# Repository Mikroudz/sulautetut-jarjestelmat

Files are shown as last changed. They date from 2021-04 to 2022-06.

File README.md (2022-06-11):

<!-- PROJECT LOGO -->
<br />
<div align="center">

<h3 align="center">Balancing robot</h3>

  <p align="center">
    Two wheeled balancing robot using 6DoF accelerometer and gyroscope.
  </p>
</div>

<!-- TABLE OF CONTENTS -->
<details>
  <summary>Table of Contents</summary>
  <ol>
    <li>
      <a href="#about-the-project">About The Project</a>
      <ul>
        <li><a href="#built-with">Built With</a></li>
      </ul>
    </li>
    <li>
      <a href="#getting-started">Getting Started</a>
      <ul>
        <li><a href="#prerequisites">Prerequisites</a></li>
        <li><a href="#installation">Installation</a></li>
      </ul>
    </li>
    <li><a href="#usage">Usage</a></li>
    <li><a href="#roadmap">Roadmap</a></li>
    <li><a href="#contributing">Contributing</a></li>
    <li><a href="#license">License</a></li>
    <li><a href="#contact">Contact</a></li>
    <li><a href="#acknowledgments">Acknowledgments</a></li>
  </ol>
</details>

<!-- ABOUT THE PROJECT -->
## About The Project

[![Product Name Screen Shot][product-screenshot]](https://example.com)

<p align="right">(<a href="#top">back to top</a>)</p>

### Built With

* [Visual Studio Code](https://code.visualstudio.com/)
* [Platformio IO](https://platformio.org/)
* [STM32PIO](https://github.com/ussserrr/stm32pio)
* [CubeMX](https://www.st.com/en/development-tools/stm32cubemx.html)

<p align="right">(<a href="#top">back to top</a>)</p>

<!-- GETTING STARTED -->
## Getting Started

Easiest way to develop is with Visual Studio Code and Platformio. Template file generated with CubeMX and converted to VSCode format with STM32PIO. All tools work in both linux and windows operating systems. To program and debug the PCB, stlink interface is used and it requires a Nucleo development board or a Stlink programmer.

### Installation

1. Install Visual Studio Code for your distribution

2. Install Platformio IO inside Visual Studio Code.

3. Clone the project to your local PC
   ```sh
   git clone https://github.com/Mikroudz/sulautetut-jarjestelmat.git
   ```
4. Open project folder "STM32F410" in Visual Studio Code. Platformio should detect the project and install required compilation tools. Wait till it finishes.

## Programming the device
1. Connect a JTAG programming interface to the device and a Nucleo programmir header or JTAG programmer.

2. Power up the PCB with 11 - 16 volt power supply.

3. Insert USB to a pc with Visual Studio and platformio installed. The STM32 programmer should be detected.

4. Compile and program the device by pressing "Program" button in bottom of VSCode screen.

5. If successful the robots led should blink slowly.

<p align="right">(<a href="#top">back to top</a>)</p>

### Making configuration changes

To change I/O port configurations or device clocks, the project has been configured to use CubeMX tool. 
WARNING: if configurations are changed directly in the code, they will be overwritten by CubeMX.

1. Install CubeMX and open STM32F410.ioc file in the program.

2. Make changes and save the file.

3. Run [STM32PIO](https://github.com/ussserrr/stm32pio) on command line to update the project files:
   ```sh
   stm32pio generate -d path/to/ioc/file/folder
   ```

<!-- USAGE EXAMPLES -->
## Usage

After powering the robot and without LoRa connection it should be ready to balance. If the leds are blinking then hold the robot in upright position until it start to balance. If robot falls over too much forward or backwards, it stops the motors. 

<p align="right">(<a href="#top">back to top</a>)</p>

<!-- LICENSE -->
## License

Distributed under the MIT License. See `LICENSE.txt` for more information.

<p align="right">(<a href="#top">back to top</a>)</p>

<!-- ACKNOWLEDGMENTS -->
## Acknowledgments

* [@Mikroudz](https://github.com/Mikroudz)
* [@jruntti20](https://github.com/jruntti20)
* [@valtteriah](https://github.com/valtteriah)

<p align="right">(<a href="#top">back to top</a>)</p>

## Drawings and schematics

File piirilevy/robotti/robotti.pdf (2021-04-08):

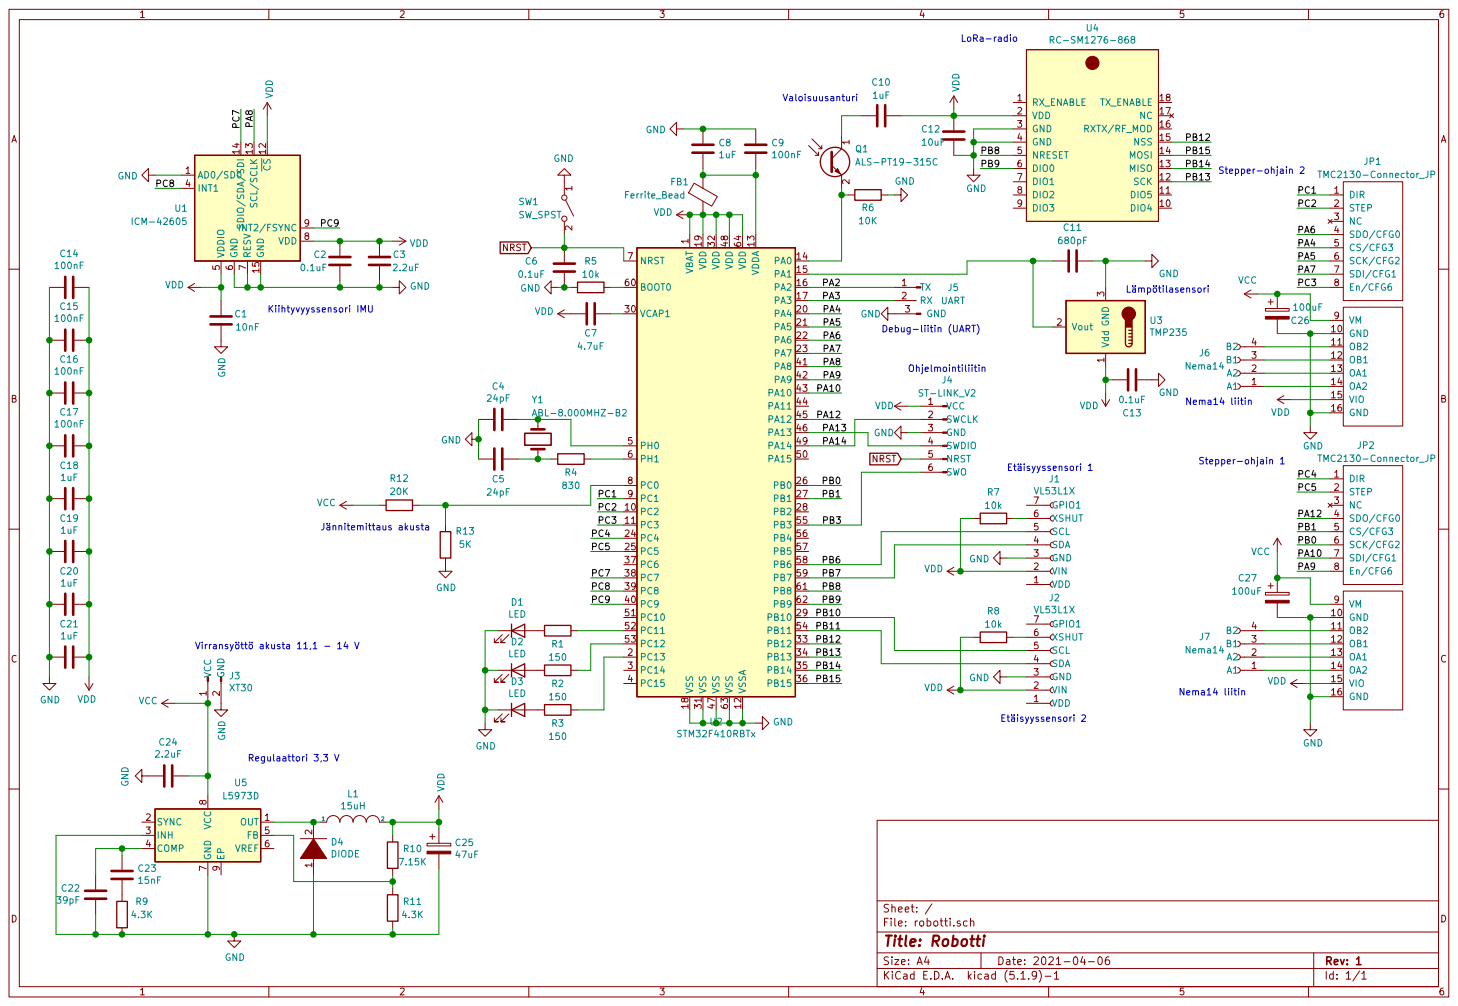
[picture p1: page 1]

LoRa-radioEtäisyyssensori 1
1uF GND
Stepper-ohjain 2 Nema14 liitin Nema14 liitin

1 VCAP1 30 VDD 19 VDD 32 VDD 48 VDD 64 VDDA 13 VSS 18 VSS 31 VSS 47 VSS 63 VSSA 12 U2 STM32F410RBTx

VCC 1 SWCLK 2 GND 3 SWDIO 4 NRST 5 SWO 6

Id: 1/1 Title: Robotti File: robotti.sch Sheet: / R12

VDD 1 VIN 2 GND 3 SDA 4 SCL 5 XSHUT 6 GPIO1 7

Jännitemittaus akusta Virransyöttö akusta 11,1 - 14 V

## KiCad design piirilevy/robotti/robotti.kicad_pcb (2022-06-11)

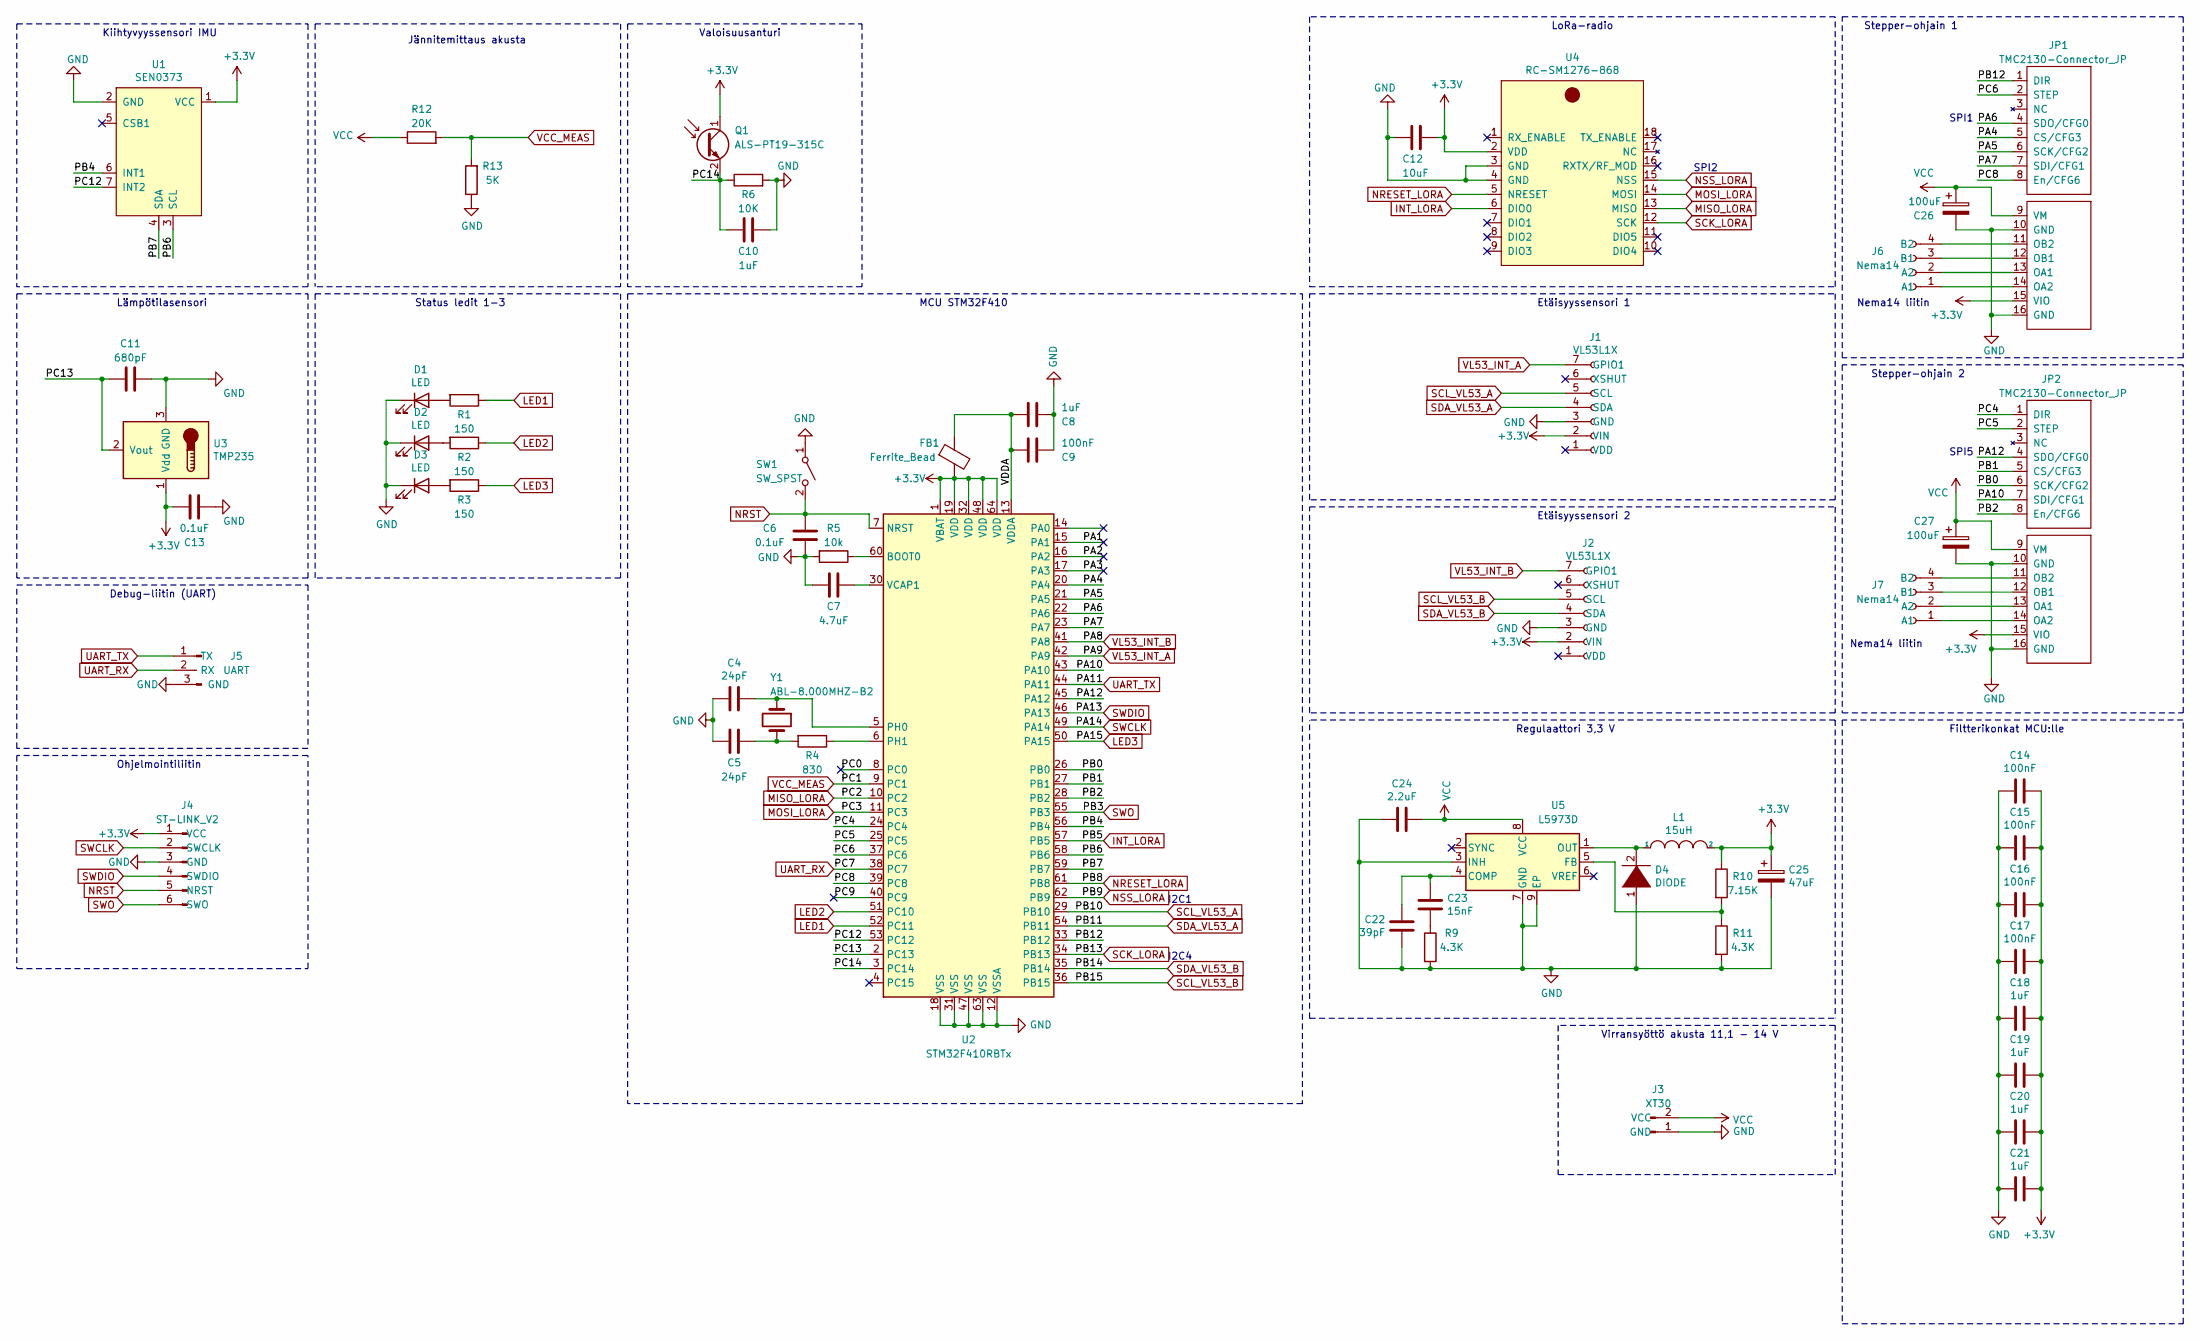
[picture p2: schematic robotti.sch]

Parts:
C4, C5: 24pF; C_0805_2012Metric
C6, C13: 0.1uF; C_0805_2012Metric
C7: 4.7uF; C_0805_2012Metric
C8, C10, C18, C19, C20, C21: 1uF; C_0805_2012Metric
C9, C14, C15, C16, C17: 100nF; C_0805_2012Metric
C11: 680pF; C_0805_2012Metric
C12: 10uF; C_0805_2012Metric
C22: 39pF; C_0805_2012Metric
C23: 15nF; C_0805_2012Metric
C24: 2.2uF; C_0805_2012Metric
C25: 47uF; CP_Elec_6.3x5.4_Nichicon
C26, C27: 100uF; CP_Elec_8x5.4
D1, D2, D3: LED; LED_0805_2012Metric
D4: DIODE; D_SMB
FB1: Ferrite_Bead; R_0805_2012Metric
J1, J2: VL53L1X; JST_SH_BM07B-SRSS-TB_1x07-1MP_P1.00mm_Vertical
J3: XT30; AMASS_XT30U-F_1x02_P5.0mm_Vertical
J4: ST-LINK_V2; PinHeader_1x06_P2.54mm_Vertical
J5: UART; PinHeader_1x03_P2.54mm_Vertical
J6, J7: Nema14; JST_PH_B4B-PH-K_1x04_P2.00mm_Vertical
JP1, JP2: TMC2130-Connector_JP; TMC2130
L1: 15uH; L_Bourns_SRR1260
Q1: ALS-PT19-315C; D_1206_3216Metric_Pad1.42x1.75mm_HandSolder
R1, R2, R3: 150; R_0805_2012Metric
R4: 830; R_0805_2012Metric
R5: 10k; R_0805_2012Metric
R6: 10K; R_0805_2012Metric
R9, R11: 4.3K; R_0805_2012Metric
R10: 7.15K; R_0805_2012Metric
R12: 20K; R_0805_2012Metric
R13: 5K; R_0805_2012Metric
SW1: SW_SPST; SW_SPST_TL3305A
U1: SEN0373; PinHeader_1x07_PinHeader_SEN0373
U2: STM32F410RBTx; LQFP-64_10x10mm_P0.5mm
U3: TMP235; SOT-323_SC-70
U4: RC-SM1276-868
U5: L5973D; HSOP-8-1EP_3.9x4.9mm_P1.27mm_EP2.41x3.1mm_ThermalVias
Y1: ABL-8.000MHZ-B2; Crystal_HC49-U_Vertical

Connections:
/PA1: U2.15 (PA1)
/PA2: U2.16 (PA2)
/PA3: U2.17 (PA3)
/PA4: JP1.5 (CS/CFG3), U2.20 (PA4)
/PA5: JP1.6 (SCK/CFG2), U2.21 (PA5)
/PA6: JP1.4 (SDO/CFG0), U2.22 (PA6)
/PA7: JP1.7 (SDI/CFG1), U2.23 (PA7)
/PA8: J2.7 (GPIO1), U2.41 (PA8)
/PA9: J1.7 (GPIO1), U2.42 (PA9)
/PA10: JP2.7 (SDI/CFG1), U2.43 (PA10)
/PA11: J5.1 (TX), U2.44 (PA11)
/PA12: JP2.4 (SDO/CFG0), U2.45 (PA12)
/PA13: J4.4 (SWDIO), U2.46 (PA13)
/PA14: J4.2 (SWCLK), U2.49 (PA14)
/PA15: R3.1, U2.50 (PA15)
/PB0: JP2.6 (SCK/CFG2), U2.26 (PB0)
/PB1: JP2.5 (CS/CFG3), U2.27 (PB1)
/PB2: JP2.8 (En/CFG6), U2.28 (PB2)
/PB3: J4.6 (SWO), U2.55 (PB3)
/PB4: U1.6 (INT1), U2.56 (PB4)
/PB5: U2.57 (PB5), U4.6 (DIO0)
/PB6: U1.3 (SCL), U2.58 (PB6)
/PB7: U1.4 (SDA), U2.59 (PB7)
/PB8: U2.61 (PB8), U4.5 (NRESET)
/PB9: U2.62 (PB9), U4.15 (NSS)
/PB10: J1.5 (SCL), U2.29 (PB10)
/PB11: J1.4 (SDA), U2.54 (PB11)
/PB12: JP1.1 (DIR), U2.33 (PB12)
/PB13: U2.34 (PB13), U4.12 (SCK)
/PB14: J2.4 (SDA), U2.35 (PB14)
/PB15: J2.5 (SCL), U2.36 (PB15)
/PC0: U2.8 (PC0)
/PC1: R12.2, R13.2, U2.9 (PC1)
/PC2: U2.10 (PC2), U4.13 (MISO)
/PC3: U2.11 (PC3), U4.14 (MOSI)
/PC4: JP2.1 (DIR), U2.24 (PC4)
/PC5: JP2.2 (STEP), U2.25 (PC5)
/PC6: JP1.2 (STEP), U2.37 (PC6)
/PC7: J5.2 (RX), U2.38 (PC7)
/PC8: JP1.8 (En/CFG6), U2.39 (PC8)
/PC9: U2.40 (PC9)
/PC12: U1.7 (INT2), U2.53 (PC12)
/PC13: C11.1, U2.2 (PC13), U3.2 (Vout)
/PC14: C10.1, Q1.2 (E), R6.1, U2.3 (PC14)
/VDDA: C8.2, C9.2, FB1.1, U2.13 (VDDA)
GND: C4.2, C5.2, C6.2, C7.1, C8.1, C9.1, C10.2, C11.2, C12.2, C13.1, C14.1, C15.1, C16.1, C17.1, C18.2, C19.2, C20.2, C21.2, C22.1, C24.1, C25.2, C26.2, C27.2, D1.1 (K), D2.1 (K), D3.1 (K), D4.1 (K), J1.3 (GND), J2.3 (GND), J3.1 (GND), J4.3 (GND), J5.3 (GND), JP1.10 (GND), JP1.16 (GND), JP2.10 (GND), JP2.16 (GND), R5.2, R6.2, R9.2, R11.2, R13.1, SW1.1 (A), U1.2 (GND), U2.12 (VSSA), U2.18 (VSS), U2.31 (VSS), U2.47 (VSS), U2.63 (VSS), U3.3 (GND), U4.3 (GND), U4.4 (GND), U5.3 (INH), U5.7 (GND), U5.9 (EP)
NRST: C6.1, J4.5 (NRST), SW1.2 (B), U2.7 (NRST)
unnamed: C4.1, U2.5 (PH0), Y1.1
unnamed: C5.1, R4.2, Y1.2
unnamed: C7.2, U2.30 (VCAP1)
unnamed: C22.2, C23.2, U5.4 (COMP)
unnamed: C23.1, R9.1
unnamed: D1.2 (A), R1.2
unnamed: D2.2 (A), R2.2
unnamed: D3.2 (A), R3.2
unnamed: D4.2 (A), L1.1, U5.1 (OUT)
unnamed: J6.1 (A1), JP1.14 (OA2)
unnamed: J6.2 (A2), JP1.13 (OA1)
unnamed: J6.3 (B1), JP1.12 (OB1)
unnamed: J6.4 (B2), JP1.11 (OB2)
unnamed: J7.1 (A1), JP2.14 (OA2)
unnamed: J7.2 (A2), JP2.13 (OA1)
unnamed: J7.3 (B1), JP2.12 (OB1)
unnamed: J7.4 (B2), JP2.11 (OB2)
unnamed: R1.1, U2.52 (PC11)
unnamed: R2.1, U2.51 (PC10)
unnamed: R4.1, U2.6 (PH1)
unnamed: R5.1, U2.60 (BOOT0)
unnamed: R10.2, R11.1, U5.5 (FB)
VCC: C24.2, C26.1, C27.1, J3.2 (VCC), JP1.9 (VM), JP2.9 (VM), R12.1, U5.8 (VCC)
VDD: C12.1, C13.2, C14.2, C15.2, C16.2, C17.2, C18.1, C19.1, C20.1, C21.1, C25.1, FB1.2, J1.2 (VIN), J2.2 (VIN), J4.1 (VCC), JP1.15 (VIO), JP2.15 (VIO), L1.2, Q1.1 (C), R10.1, U1.1 (VCC), U2.1 (VBAT), U2.19 (VDD), U2.32 (VDD), U2.48 (VDD), U2.64 (VDD), U3.1 (Vdd), U4.2 (VDD)

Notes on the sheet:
Regulaattori 3,3 V
Virransyöttö akusta 11,1 - 14 V
Kiihtyvyyssensori IMU
Lämpötilasensori
Ohjelmointiliitin
Etäisyyssensori 1
Etäisyyssensori 2
Jännitemittaus akusta
Debug-liitin (UART)
Stepper-ohjain 2
Nema14 liitin
LoRa-radio
Valoisuusanturi
SPI5
SPI1
SPI2
I2C4
I2C1
Stepper-ohjain 1
Filtterikonkat MCU:lle
MCU STM32F410
Status ledit 1-3

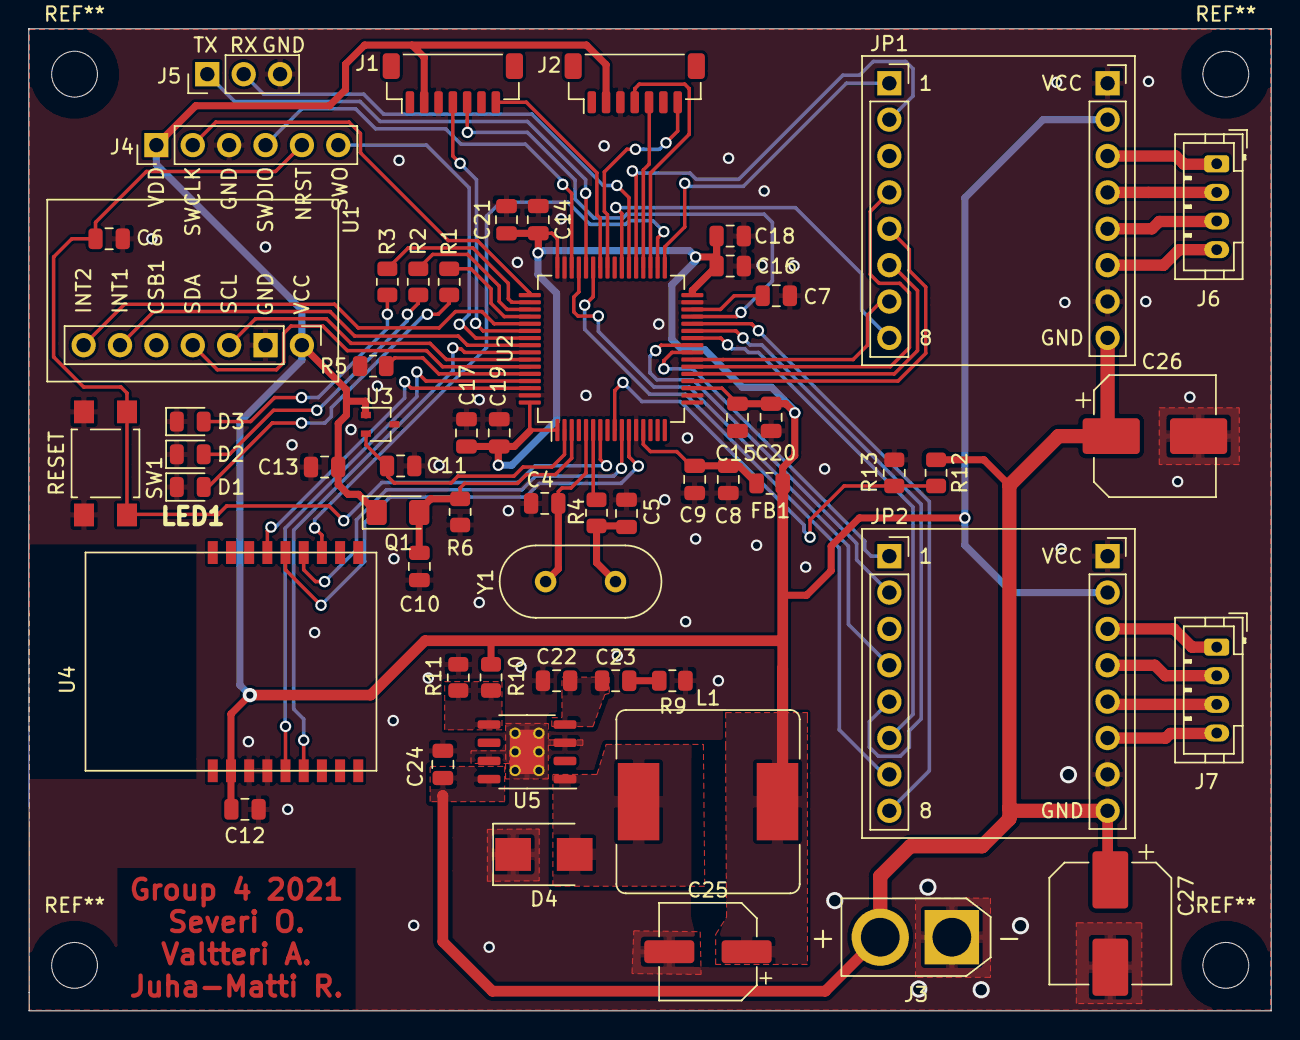
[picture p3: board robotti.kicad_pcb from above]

Board: 2 copper layers, 86.8 x 68.6 mm, 58 parts (0 on the bottom side), 66 nets.

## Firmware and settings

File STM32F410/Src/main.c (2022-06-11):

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
/* Includes ------------------------------------------------------------------*/
#include "main.h"
#include "adc.h"
#include "dma.h"
#include "fmpi2c.h"
#include "i2c.h"
#include "spi.h"
#include "tim.h"
#include "usart.h"
#include "gpio.h"
#include "VL53L1X_api.h"
#include "VL53L1X_calibration.h"
#include "vl53l1_platform.h"
#include "vl53l1_types.h"
#include "vl53l1_error_codes.h"

/* USER CODE BEGIN Includes */
#include "lora_sx1276.h"
#include "bmx160.h"
#include "stepper.h"
#include "motion_control.h"
#include "lora_app.h"

/* USER CODE END Includes */

/* USER CODE BEGIN PD */
#define VL53_int_GPIO_Port GPIO_PIN_9
/* USER CODE END PD */


/* USER CODE BEGIN PV */
volatile uint8_t imu_data_status = IMU_DATA_PENDING;
volatile uint8_t lora_rx_status = LORA_RX_DATA_PENDING;
volatile uint8_t adc_data_status = ADC_DATA_PENDING;
volatile uint8_t uart_data_pending = 0;

uint8_t UART6_rxBuffer;
uint8_t uart_rx_buf[32];
Stepper_HandleTypeDef step1;
Stepper_HandleTypeDef step2;

//ADC 
uint16_t adc_raw = 0;
int steps = 0;
/* USER CODE END PV */

//VL53L1
uint16_t dev = 0x52;
int VL53L1X_status = 0;
volatile int IntCount;
volatile int loopCount = 0;
#define isInterrupt 0
I2C_HandleTypeDef hi2c2;

void SystemClock_Config(void);
/* USER CODE BEGIN 0 */

void adc_start(void){

    HAL_ADC_Start_IT(&hadc1);
    //HAL_ADC_PollForConversion(&hadc1, 1000);
    //uint16_t adc_raw = HAL_ADC_GetValue(&hadc1);
    //float voltage_meas = (float)adc_raw * (3.27 / 4095.0) * 5.0;
}

//int _write(int fd, char * ptr, int len){
//  HAL_UART_Transmit(&huart6, (uint8_t *)ptr, len, 0xffff);
//  return len;
//}

void HAL_GPIO_EXTI_Callback_TOF(uint16_t GPIO_Pin)
{
		if (GPIO_Pin==VL53_int_GPIO_Port)
		{
			IntCount++;
		}
}

/* USER CODE END 0 */

/**
  * @brief  The application entry point.
  * @retval int
  */
int main(void)
{
  /* MCU Configuration--------------------------------------------------------*/

  /* Reset of all peripherals, Initializes the Flash interface and the Systick. */
  HAL_Init();

  /* Configure the system clock */
  SystemClock_Config();

  /* Initialize all configured peripherals */
  MX_GPIO_Init();
  MX_DMA_Init();
  MX_FMPI2C1_Init();
  MX_I2C1_Init();
  MX_I2C2_Init();
  MX_SPI1_Init();
  MX_SPI2_Init();
  MX_SPI5_Init();
  MX_USART6_UART_Init();
  MX_TIM5_Init();
  MX_TIM6_Init();
  MX_ADC1_Init();
  MX_TIM9_Init();
  /* USER CODE BEGIN 2 */


  HAL_Delay(100);
  RetargetInit(&huart6);

  uint32_t last_run_balance = 0;
  uint32_t last_read_voltage = 0;
  uint32_t last_blink = 0;
  uint32_t last_run_comp = 0;
  uint32_t last_lora_tx = 0;
  uint32_t last_lora_meas = 0;
  uint32_t last_dist_meas = 0;


  MainState_t app_state = STOP;

  MoveDirection_t robot_move = MOVE_STOP;

  lora_sx1276 lora;
  // Lora Nreset
  HAL_GPIO_WritePin(GPIOB, GPIO_PIN_8, GPIO_PIN_SET);


  // SX1276 compatible module connected to SPI2, NSS pin connected to GPIO with label LORA_NSS
  uint8_t res = lora_init(&lora, &hspi2, GPIOB, GPIO_PIN_9, LORA_BASE_FREQUENCY_EU);
  if (res != LORA_OK) {
    // Initialization failed
    printf("Lora ei init koodi: %d\n", res);
    app_state = INIT_FAIL;
  }else
    printf("lora init DONE\n");

  bmx160 imu;
  uint8_t imu_status = bmx160_init(&imu, &hi2c1, GPIOA, GPIO_PIN_8);

  while(imu_status > 0){
    printf("IMU init kusi, pysaytetaan: %d\n", imu_status);
    app_state = INIT_FAIL;
    HAL_Delay(1000);
  }
  // Run this only to get IMU calibration parameters
  //bmx160_calibrate(&imu);

  init_stepper(&step1, &htim5, &hspi1, 
              tmc2130_1_step_GPIO_Port, tmc2130_1_step_Pin,
              tmc2130_1_dir_GPIO_Port, tmc2130_1_dir_Pin, 
              tmc2130_1_enable_GPIO_Port, tmc2130_1_enable_Pin, 
              tmc2130_1_nss_GPIO_Port, tmc2130_1_nss_Pin);
  init_stepper(&step2, &htim9, &hspi5, 
              tmc2130_2_step_GPIO_Port, tmc2130_2_step_Pin,
              tmc2130_2_dir_GPIO_Port,tmc2130_2_dir_Pin,    
              tmc2130_2_enable_GPIO_Port, tmc2130_2_enable_Pin, 
              tmc2130_2_nss_GPIO_Port, tmc2130_2_nss_Pin);

  //**** PID CONTROLLER INIT ****//
  PID_TypeDef velocityPID = {.KP = 0.45, .KI = 0.25, .KD = 0.005, 
                            .min = -13., .max = 13., .target = 0.};

  PID_TypeDef anglePID= {.KP = 150., .KI = .05 , .KD = 1.2,
                          .min = -1500, .max = 1500, 
                          .target = 1.5};

  //**** LORA RECEIVE START ****//
  uint8_t lora_rx_buffer[128];
  // interrupt on receive
  lora_enable_interrupt_rx_done(&lora);
  // Put LoRa modem into continuous receive mode
  lora_mode_receive_continuous(&lora);

  //**** LORA RECEIVE END ****//
  HAL_Delay(10);

  HAL_UART_Receive_IT(&huart6, uart_rx_buf, 2);

  uint8_t running = 0;
  uint8_t balance_setup = 0;
  // remember stepper "speed"
  int last_step_count = 0;
  // Main loop iteration counter
  uint32_t iter = 0;
  // robot tilt
  float real_pitch = 0;
  // Offsets to motor speed while turning
  int left_motor_offset = 0, right_motor_offset = 0;
  // voltage filtering
  uint16_t battery_meas[4] = {0};
  uint8_t battery_meas_pos = 0;
  // measurement results for sending
  RobotData_t robot_data;

  app_state = APP_RUN;

  /// VL53L1X code starts here
  uint8_t byteData, sensorState=0;
  uint16_t wordData;
  uint8_t ToFSensor = 1; // 0=Left, 1=Center(default), 2=Right
  uint16_t Distance;
  uint16_t SignalRate;
  uint16_t AmbientRate;
  uint16_t SpadNum; 
  uint8_t RangeStatus;
  uint8_t dataReady;

  ToFSensor = 1; // Select ToFSensor: 0=Left, 1=Center, 2=Right
  //status = VLO53L1_ResetId(ToFSensor, 0); // Reset ToF sensor
  HAL_Delay(2);
  char text[] = "Huart ulostulo toimii.\n";
  HAL_UART_Transmit(&huart6, (uint8_t*)&text, 23, 0xFFFF);

  /* Those basic I2C read functions can be used to check your own I2C functions */
  VL53L1X_status = VL53L1_RdByte(dev, 0x010F, &byteData);
  printf("status: %d\n",VL53L1X_status);
  printf("VL53L1X Model_ID: %X\n", byteData);
  VL53L1X_status = VL53L1_RdByte(dev, 0x0110, &byteData);
  printf("VL53L1X Module_Type: %X\n", byteData);
  VL53L1X_status = VL53L1_RdWord(dev, 0x010F, &wordData);
  printf("VL53L1X: %X\n", wordData);
  while(sensorState==0){
    //printf("Booting VL53L1X...\n");
    VL53L1X_status = VL53L1X_BootState(dev, &sensorState);
    //printf("Sensorstate: %d\n", sensorState);
    HAL_Delay(10);
  }
  printf("Chip booted\n");

  /* This function must to be called to initialize the sensor with the default setting  */
  VL53L1X_status = VL53L1X_SensorInit(dev);

  /* Optional functions to be used to change the main ranging parameters according the application requirements to get the best ranging performances */
  VL53L1X_status = VL53L1X_SetDistanceMode(dev, 2); /* 1=short, 2=long */
  VL53L1X_status = VL53L1X_SetTimingBudgetInMs(dev, 100); /* in ms possible values [20, 50, 100, 200, 500] */
  VL53L1X_status = VL53L1X_SetInterMeasurementInMs(dev, 200); /* in ms, IM must be > = TB */
  printf("VL53L1X Ultra Lite Driver Example running ...\n");
  VL53L1X_status = VL53L1X_StartRanging(dev);   /* This function has to be called to enable the ranging */
  /* USER CODE END 2 */

  /* Infinite loop */
  /* USER CODE BEGIN WHILE */
  while (1){
    /* USER CODE END WHILE */

    /* USER CODE BEGIN 3 */
    if(HAL_GetTick() - last_run_comp > CALC_COMP){
      // run comple50 filter on raw IMU values.
      real_pitch = complementary_filter(&imu.acc, &imu.gyro, real_pitch);
      // trigger new imu data fetch
      imu_start_update(&imu);
      last_run_comp = HAL_GetTick();
    }

    // main balance loop
    if(HAL_GetTick() - last_run_balance > CALC_BALANCE){
      last_run_balance = HAL_GetTick();

      //printf("pitch: %d \n", (int)real_pitch);

      if(abs((int)(real_pitch - 90.)) < 30 && app_state == APP_RUN)
        running = 1; // start balancing
      else{
        running = 0;
      }

      //printf("pitch: %d\n", (int)(real_pitch - 85.));
      if(uart_data_pending){
          uart_data_pending = 0;
          if(uart_rx_buf[0] == '8'){
            robot_move = MOVE_FORWARD;
          }
          if(uart_rx_buf[0] == '2'){
            robot_move = MOVE_REVERSE;
          }
          if(uart_rx_buf[0] == '5'){
            robot_move = MOVE_STOP;
          }

          if(uart_rx_buf[0] == '9'){
            anglePID.KD += 0.5;
          }
          if(uart_rx_buf[0] == '6'){
            robot_move = TURN_RIGHT;
            //anglePID.KD -= 0.5;
          }


          if(uart_rx_buf[0] == '8'){
            velocityPID.KP += 0.01;
          }
          if(uart_rx_buf[0] == '5'){
            velocityPID.KP -= 0.01;
          }

          if(uart_rx_buf[0] == '7'){
            velocityPID.KD += 0.002;
          }
          if(uart_rx_buf[0] == '4'){
            robot_move = TURN_LEFT;
            //velocityPID.KD -= 0.002;
          }


          if(uart_rx_buf[0] == '1'){
            anglePID.KP += 1.;
          }
          if(uart_rx_buf[0] == '0'){
            anglePID.KP -= 1.;
          }

          printf("velocity ");
          print_pid(&velocityPID);
          printf("angle ");
          print_pid(&anglePID);
          HAL_UART_Receive_IT(&huart6, uart_rx_buf, 2);
        }
      // tasapainotus
      if(running){
        // first round when starting
        if(balance_setup == 1){

          stepper_setspeed(&step1, 0);
          stepper_setspeed(&step2, 0);
          enable_stepper(&step1);
          enable_stepper(&step2);
          pid_reset(&anglePID);
          pid_reset(&velocityPID);
        
          balance_setup++;
          step1.step_count = 0;
          last_step_count = 0;
        }else if(balance_setup > 0){
          // wait for upright position
          if(fabs(real_pitch - 90.) < 3.){
            if(balance_setup < 30)
              balance_setup++;
            else{
              balance_setup = 0;
              // init values used in calculations
              anglePID.last = real_pitch - 90.;
            }
          }
        }else{ // actual balance
          
        // 90 asteen korjaus. Tää pitäs tehä erilailla koska aiheuttaa gimbal lockkia
        anglePID.new = real_pitch - 90.;
        // PID, joka antaa moottorinopeuden
        int target_speed = (int)pid_steps(&anglePID);
        // lasketaan joka toinen kierros kulman korjaus perustuen robotin oikeaan nopeuteen
        if (iter % 2 == 0){
          // Nopeus arvioidaan kalmanfiltterillä koska stepit eivät ole robotin oikea fyysinen nopeus
          velocityPID.new = kalmanfilter((float)(step1.step_count - last_step_count));
          last_step_count = step1.step_count;
          if(robot_move == MOVE_FORWARD){
            // unohda integraali kun liikutaan; muistetaan taas kun ollaan paikallaan
            velocityPID.out_sum = 0.;
            if(velocityPID.target < 15)
              velocityPID.target += 0.5;
          }else if(robot_move == MOVE_REVERSE){
            velocityPID.out_sum = 0.;
            if(velocityPID.target > -15)
              velocityPID.target -= .5;
          }else if(robot_move == MOVE_STOP){
            velocityPID.target = 0.;
          }


          // asetetaan kohdekulma välillä +10 -10
          anglePID.target = -pid_steps(&velocityPID);
        }


        switch(robot_move){
          case TURN_LEFT:
            left_motor_offset = 200;
            right_motor_offset = -100;
          break;
          case TURN_RIGHT:
            left_motor_offset = -200;
            right_motor_offset = 100;
          break;

          default:
            left_motor_offset = 0;
            right_motor_offset = 0;

        }

        //printf("target angle: %d current speed: %d speed target: %d angle: %d steps: %d \n", 
        //(int)anglePID.target, (int) velocityPID.new, target_speed, (int)real_pitch, step1.step_count );
        // stepperien nopeuden asettaminen

        stepper_setspeed(&step1, -(target_speed + left_motor_offset));
        stepper_setspeed(&step2, target_speed + right_motor_offset);
        iter++;
        }
      }else{
          disable_stepper(&step1);
          disable_stepper(&step2);
          balance_setup = 1;
        }
    }

    // Read voltage to adc_raw every READ_VOLTAGE
    if(HAL_GetTick() - last_read_voltage > READ_VOLTAGE){
      float voltage_meas = 0;
      if(adc_raw > 0){
        battery_meas[battery_meas_pos] = adc_raw;
        if(battery_meas_pos < 4)
          battery_meas_pos++;
        else
          battery_meas_pos = 0;
        uint8_t meas_count = 0;
        uint32_t batt_total = 0;
        for(int i = 0; i < 4; i++){
          if(battery_meas[i] > 0){
            meas_count++;
            batt_total += battery_meas[i];
          }
        }
        robot_data.voltage = (uint16_t)(batt_total / meas_count);
        voltage_meas = (float)(batt_total / meas_count) * (3.27 / 4095.0) * 5.0;
        if(voltage_meas < BATTERY_LOW){
          app_state = LOW_BATTERY;
          printf("Low voltage <11.1 \n");
        }
      }
      adc_start();
      last_read_voltage = HAL_GetTick();
    }


    // Check if imu data is ready to be read
    if(imu_data_status == IMU_DATA_READY){
      // update values in imu structure. Read them like imu.acc.x etc...
      imu_end_update(&imu);
      // print values (for debug only)
      //imu_print_values(&imu);
      imu_data_status = IMU_DATA_PENDING;
    }
    
    // TODO: move this to a function
    if(lora_rx_status == LORA_RX_DATA_READY){
      // LoRa receive check
      // Wait for packet up to 10sec
      uint8_t res;
      uint8_t len = lora_receive_packet_blocking(&lora, lora_rx_buffer, sizeof(lora_rx_buffer), 10000, &res);

      //uint8_t len = lora_receive_packet_blocking(&lora, lora_rx_buffer, sizeof(lora_rx_buffer), 10000, &res);
      if (res != LORA_OK) {
        printf("Receive faile, code: %d\n", res);
        // Receive failed
      }
      lora_rx_buffer[len] = 0;  // null terminate string to print it
      printf("Lora buff len: %d\n", len);
      printf("Lora RSSI: %d\n", lora_packet_rssi(&lora));
      printf("Lora SNR: %d\n", lora_packet_snr(&lora));

      for(int i = 0; i < len; i++){
        printf("0x%x ", lora_rx_buffer[i]);
      }
      printf("\n");

      lora_parse_message(lora_rx_buffer);
      robot_move = (MoveDirection_t)lora_rx_buffer[0];
      
      
     // printf("'%s'\n", lora_rx_buffer);
      lora_rx_status = LORA_RX_DATA_PENDING;
    }


    // Check if adc (voltage) is correctly read and print it.
    //if(adc_data_status == ADC_DATA_READY){
    //  char * buf[6];
    //  gcvt((float)adc_raw * (3.27 / 4095.0) * 5.0, 3, buf);
      //printf("ADC val: %s\n", buf);
    //  adc_data_status = ADC_DATA_PENDING;
    //}


    // blink one led every second
    if(HAL_GetTick() - last_blink > BLINK_LED){

      HAL_GPIO_TogglePin(GPIOC, GPIO_PIN_11);
      HAL_GPIO_TogglePin(GPIOC, GPIO_PIN_10);
      //HAL_GPIO_TogglePin(GPIOA, GPIO_PIN_15);
      if(running)
        last_blink = HAL_GetTick();
      else
        last_blink = HAL_GetTick() - 900;
    }

    // poll if we have messages to send
    if(HAL_GetTick() - last_lora_tx > SEND_LORA_TX){

      uint8_t tx_len = 0;
      uint8_t lora_tx_msg[15] = {};

      if(last_lora_meas % 5 == 0){
        tx_len = lora_create_measurement_message(&robot_data, lora_tx_msg);
        last_lora_meas = 0;
      }else if(robot_data.send_pid == PID_SEND_ANGLE){
        tx_len = lora_create_pid_message(&anglePID, lora_tx_msg, 'A');
        robot_data.send_pid = PID_SEND_ANGLE;
      }else if(robot_data.send_pid == PID_SEND_VELOCITY){
        tx_len = lora_create_pid_message(&velocityPID, lora_tx_msg, 'V');
        robot_data.send_pid = 0;
      }


      // actually send data if we have any
      if (tx_len > 0){
        uint8_t res = lora_send_packet_blocking(&lora, lora_tx_msg, tx_len, 1000);
        if (res != LORA_OK) {
          printf("Send fail: %d\n", res);
        // Send failed
        }
        printf("lora send\n");
        
        lora_mode_receive_continuous(&lora);
      }

      last_lora_meas++;
      last_lora_tx = HAL_GetTick();
    }

    // Send packet can be as simple as
    // Receive buffer
    //lora_receivetest(&lora);
    //uint8_t res = lora_send_packet(&lora, (uint8_t *)"INF", 3);
    //if (res != LORA_OK) {
    //  printf("Send fail: %d\n", res);
      // Send failed
    //}

    //////////////// 
    //VL53L1X code//
    ////////////////

    if (HAL_GetTick() - last_dist_meas > CALC_DISTANCE){
      while(dataReady == 0){
        VL53L1X_status = VL53L1X_CheckForDataReady(dev, &dataReady);
      }
      last_dist_meas = HAL_GetTick();
      if(dataReady != 0){
        dataReady = 0;
        VL53L1X_status = VL53L1X_GetRangeStatus(dev, &RangeStatus);
        VL53L1X_status = VL53L1X_GetDistance(dev, &Distance);
        VL53L1X_status = VL53L1X_GetSignalRate(dev, &SignalRate);
        VL53L1X_status = VL53L1X_GetAmbientRate(dev, &AmbientRate);
        VL53L1X_status = VL53L1X_GetSpadNb(dev, &SpadNum);
        VL53L1X_status = VL53L1X_ClearInterrupt(dev); /* clear interrupt has to be called to enable next interrupt*/
        printf("%u, %u, %u, %u, %u\n", RangeStatus, Distance, SignalRate, AmbientRate,SpadNum);
        robot_data.distance_front = Distance;
      }
    }
    
  }

}

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
/* USER CODE BEGIN 4 */

void HAL_UART_RxCpltCallback(UART_HandleTypeDef *huart){
    uart_data_pending = 1;
}

// ajastininterruptit
void HAL_TIM_PeriodElapsedCallback(TIM_HandleTypeDef* htim){
  if(htim->Instance == TIM5){ // stepper 1
    update_stepper(&step1);
  }else if(htim->Instance == TIM9){ // stepper 2
    update_stepper(&step2);
  }
}

// pin ch 5-9 callback. Loralle
void HAL_GPIO_EXTI_Callback(uint16_t GPIO_Pin){
  if(GPIO_Pin == lora_int_Pin){
    lora_rx_status = LORA_RX_DATA_READY;
  }
}

// ADC callback
void HAL_ADC_ConvCpltCallback(ADC_HandleTypeDef* hadc){
  adc_raw = HAL_ADC_GetValue(&hadc1);
  adc_data_status = ADC_DATA_READY;
}

// i2c dma callback imulle
// FYI myös eventit pitää olla I2C:lle päällä cubemx:Stä että tää toimii
void HAL_I2C_MasterRxCpltCallback (I2C_HandleTypeDef * hi2c){
  //if (hi2c->Instance==hi2c1.Instance){ 
  //   HAL_DMA_Abort_IT(hi2c->hdmarx);
  // }
  imu_data_status = IMU_DATA_READY;
}


// LoRa SPI callback RX done
void HAL_SPI_RxCpltCallback(SPI_HandleTypeDef *hspi){
  //if(hspi->Instance == )
  HAL_GPIO_WritePin(GPIOB, GPIO_PIN_9, GPIO_PIN_RESET);
}
/* USER CODE END 4 */
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


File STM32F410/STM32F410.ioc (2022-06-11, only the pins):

Mcu.UserName=STM32F410RBTx
PA10.Signal=SPI5_MOSI
PA11.Signal=USART6_TX
PA12.Signal=SPI5_MISO
PA13.Signal=SYS_JTMS-SWDIO
PA14.Signal=SYS_JTCK-SWCLK
PA15.GPIO_Label=LED3
PA15.Signal=GPIO_Output
PA4.GPIO_Label=tmc2130_1_nss
PA4.Signal=GPIO_Output
PA5.Signal=SPI1_SCK
PA6.Signal=SPI1_MISO
PA7.Signal=SPI1_MOSI
PA8.Signal=RCC_MCO_1
PA9.Signal=GPIO_Input
PB0.Signal=SPI5_SCK
PB1.GPIO_Label=tmc2130_2_nss
PB1.Signal=GPIO_Output
PB10.Signal=I2C2_SCL
PB11.Signal=I2C2_SDA
PB12.GPIO_Label=tmc2130_1_dir
PB12.Signal=GPIO_Output
PB13.Signal=SPI2_SCK
PB14.Signal=FMPI2C1_SDA
PB15.Signal=FMPI2C1_SCL
PB2.GPIO_Label=tmc2130_2_enable
PB2.Signal=GPIO_Output
PB3.Signal=SYS_JTDO-SWO
PB4.GPIO_Label=lora_tx_enable
PB4.Signal=GPIO_Output
PB5.GPIO_Label=lora_int
PB5.Signal=GPXTI5
PB6.GPIO_Label=IMU_I2C_SCL
PB6.Signal=I2C1_SCL
PB7.GPIO_Label=IMU_i2C_SDA
PB7.Signal=I2C1_SDA
PB8.GPIO_Label=lora_nreset
PB8.Signal=GPIO_Output
PB9.Signal=GPIO_Output
PC1.GPIO_Label=vcc_meas
PC1.Signal=SharedAnalog_PC1
PC10.Signal=GPIO_Output
PC11.Signal=GPIO_Output
PC12.GPIO_Label=lora_rx_enable
PC12.Signal=GPIO_Output
PC13-ANTI_TAMP.Signal=GPIO_Analog
PC14-OSC32_IN.Signal=GPIO_Analog
PC2.Signal=SPI2_MISO
PC3.Signal=SPI2_MOSI
PC4.GPIO_Label=tmc2130_2_dir
PC4.Signal=GPIO_Output
PC5.GPIO_Label=tmc2130_2_step
PC5.Signal=GPIO_Output
PC6.GPIO_Label=tmc2130_1_step
PC6.Signal=GPIO_Output
PC7.Signal=USART6_RX
PC8.GPIO_Label=tmc2130_1_enable
PC8.Signal=GPIO_Output
PC9.Signal=RCC_MCO_2

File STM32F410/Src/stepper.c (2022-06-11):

#include "stepper.h"

void init_stepper(Stepper_HandleTypeDef *step, TIM_HandleTypeDef *timer,
    SPI_HandleTypeDef *spi,
    GPIO_TypeDef *step_port, uint16_t step_pin,
    GPIO_TypeDef *dir_port, uint16_t dir_pin,
    GPIO_TypeDef *enable_port, uint16_t enable_pin,
    GPIO_TypeDef *nss_port, uint16_t nss_pin){
    
    assert_param(step && timer && spi);

    tmc2130_init(&step->Init.Driver, spi, enable_port, nss_port, enable_pin, nss_pin);

    step->Init.Step_Port = step_port;
    step->Init.Step_Pin = step_pin;
    step->Dir_Port = dir_port;
    step->Dir_Pin = dir_pin;
    step->Init.StepTimer = timer;
    step->Init.StepTimer->Instance->PSC = (uint16_t)50;
    step->dir = FORWARD;
    step->Init.StepTimer->Instance->ARR = 0xffff;
    step->step_delay = 0xffff;
    step->step_count = 0;
    HAL_GPIO_WritePin(dir_port, dir_pin, GPIO_PIN_RESET);
}

void disable_stepper(Stepper_HandleTypeDef *step){
    tmc2130_disable(&step->Init.Driver);
}

void enable_stepper(Stepper_HandleTypeDef *step){
    tmc2130_enable(&step->Init.Driver);
}


void stepper_setspeed(Stepper_HandleTypeDef *step, int16_t speed){
    //HAL_TIM_Base_Stop_IT(step->Init.StepTimer);
    uint16_t speed_target;
    // direction
    if(speed < 0){
        step->target_dir = BACKWARD;
        speed_target = (uint16_t)-speed;
        HAL_GPIO_WritePin(step->Dir_Port,step->Dir_Pin, GPIO_PIN_RESET);
    }else{
        speed_target = (uint16_t)speed;
        step->target_dir = FORWARD;
        HAL_GPIO_WritePin(step->Dir_Port,step->Dir_Pin, GPIO_PIN_SET);
    }
    // deadzone
    if (speed_target < 19){
        HAL_TIM_Base_Stop_IT(step->Init.StepTimer);
    }else{
        int step_speed = (60 * TIMER_FREQUENCY / STEPS_PER_ROUND) / speed_target - 1;
        step->step_delay = step_speed;
        HAL_TIM_Base_Start_IT(step->Init.StepTimer);
    }
}  

void update_stepper(Stepper_HandleTypeDef *step){
    // update timer if we have new value
    step->Init.StepTimer->Instance->ARR = (uint16_t)step->step_delay;
    // step step pin
    HAL_GPIO_TogglePin(step->Init.Step_Port, step->Init.Step_Pin);
    // count steps
    if(step->int_status)
        step->step_count += step->target_dir ? 1 : -1;
    step->int_status ^= 1;
}

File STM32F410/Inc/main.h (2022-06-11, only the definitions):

#define M_PI 3.14159265359
#define CALC_BALANCE 10 // main loop
#define BLINK_LED 100
#define READ_IMU 10
#define READ_VOLTAGE 500
#define STEPPER_UPDATE_RATE 4000
#define CALC_COMP 10
#define SEND_LORA_MEAS 1000
#define SEND_LORA_TX 100
#define CALC_DISTANCE 200
#define ADC_DATA_PENDING 0
#define ADC_DATA_READY 1
#define IMU_DATA_PENDING 1
#define IMU_DATA_READY 2
#define LORA_RX_DATA_PENDING 1
#define LORA_RX_DATA_READY 2
#define BATTERY_LOW 11.1 // volts
#define PID_SEND_ANGLE 1
#define PID_SEND_VELOCITY 2
#define vcc_meas_Pin GPIO_PIN_1
#define vcc_meas_GPIO_Port GPIOC
#define tmc2130_1_nss_Pin GPIO_PIN_4
#define tmc2130_1_nss_GPIO_Port GPIOA
#define tmc2130_2_dir_Pin GPIO_PIN_4
#define tmc2130_2_dir_GPIO_Port GPIOC
#define tmc2130_2_step_Pin GPIO_PIN_5
#define tmc2130_2_step_GPIO_Port GPIOC
#define tmc2130_2_nss_Pin GPIO_PIN_1
#define tmc2130_2_nss_GPIO_Port GPIOB
#define tmc2130_2_enable_Pin GPIO_PIN_2
#define tmc2130_2_enable_GPIO_Port GPIOB
#define tmc2130_1_dir_Pin GPIO_PIN_12
#define tmc2130_1_dir_GPIO_Port GPIOB
#define tmc2130_1_step_Pin GPIO_PIN_6
#define tmc2130_1_step_GPIO_Port GPIOC
#define tmc2130_1_enable_Pin GPIO_PIN_8
#define tmc2130_1_enable_GPIO_Port GPIOC
#define LED3_Pin GPIO_PIN_15
#define LED3_GPIO_Port GPIOA
#define lora_rx_enable_Pin GPIO_PIN_12
#define lora_rx_enable_GPIO_Port GPIOC
#define lora_tx_enable_Pin GPIO_PIN_4
#define lora_tx_enable_GPIO_Port GPIOB
#define lora_int_Pin GPIO_PIN_5
#define lora_int_GPIO_Port GPIOB
#define lora_int_EXTI_IRQn EXTI9_5_IRQn
#define IMU_I2C_SCL_Pin GPIO_PIN_6
#define IMU_I2C_SCL_GPIO_Port GPIOB
#define IMU_i2C_SDA_Pin GPIO_PIN_7
#define IMU_i2C_SDA_GPIO_Port GPIOB
#define lora_nreset_Pin GPIO_PIN_8
#define lora_nreset_GPIO_Port GPIOB

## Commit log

2021-03-25 Aloitettu piirilevysuunnittelu
    [robotti.kicad_pcb, robotti.sch]
2021-03-25 MCU lisätty, jännitesyöttö ja kide
    [robotti.sch]
2021-03-25 Lisätty LoRa, etäisyys, lämpö- ja valoisuusanturi
    [robotti.sch]
2021-04-01 korjattu lämpömittari
    [robotti.sch]
2021-04-01 lisätty toinen etäisyyssensori + annotointi symboleille
    [robotti.sch]
2021-04-01 Regulointi lisätty
    [robotti.sch]
2021-04-08 Schema valmis + aloitettu pcb
    [robotti.sch]
2021-04-22 PCB V2.0
    [robotti.kicad_pcb, robotti.sch]
2021-04-22 Generoitu Platformio IO projekti CubeMX conffista
    [robotti.kicad_pcb, robotti.sch]
2021-04-28 Lisätty I/O porttien toiminnallisuus
    [robotti.kicad_pcb]
2021-04-29 PCB korjattu ei valmis
    [robotti.kicad_pcb, robotti.sch]
2021-05-12 PCB final tilattu ver.
    [robotti-B_Cu.gbr, robotti-B_Mask.gbr, robotti-Edge_Cuts.gbr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]
2021-05-26 UART toimii
    [robotti.kicad_pcb, robotti.sch]
2021-05-27 fix schema
    [robotti.kicad_pcb, robotti.sch]
2021-05-27 (Final) korjattu pcb
    [robotti-B_Cu.gbr, robotti-B_Mask.gbr, robotti-Edge_Cuts.gbr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]
2021-06-04 LoRa testikoodi stm32f410 projektissa
2021-06-18 IMU testaus aloitettu
2021-08-12 korjaus spi read functioon
2021-08-12 Lisätty chopconf write read + bugi korjattu spi write-funktiosta
    [main.c, tmc2130.c]
2021-08-12 Lisätty stepperiajofunktio
2021-09-05 Korjattu spi-luenta stepperiltä
2021-09-08 Korjattu tmc2130 ohjausta, lisätty IMU ja lora DMA luku
2021-09-14 Toimiva koodi stepper 1 ja 2
2021-09-16 Korjattu puuttuvat interruptikäsittelijät
2021-10-11 2 stepperin tuki lisatty
    [robotti.sch]
2022-01-10 Working on new wheel position system
2022-01-12 Stepper angle control
2022-02-08 Siirretty stepperohjaimen luonti stepper-kirjaston sisaan
2022-05-12 lukee etäisyystiedot tof -sensorilta ja tallentaa lukeman robot_data.distance_front muuttujaan. Tasapainoilu toimii myös ilman DMA-ta, DMA-implementaatio vielä kesken.

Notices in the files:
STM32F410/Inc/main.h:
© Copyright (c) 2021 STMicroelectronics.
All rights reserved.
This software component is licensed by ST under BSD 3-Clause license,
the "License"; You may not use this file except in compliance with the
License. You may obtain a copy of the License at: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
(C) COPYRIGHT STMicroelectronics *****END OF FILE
